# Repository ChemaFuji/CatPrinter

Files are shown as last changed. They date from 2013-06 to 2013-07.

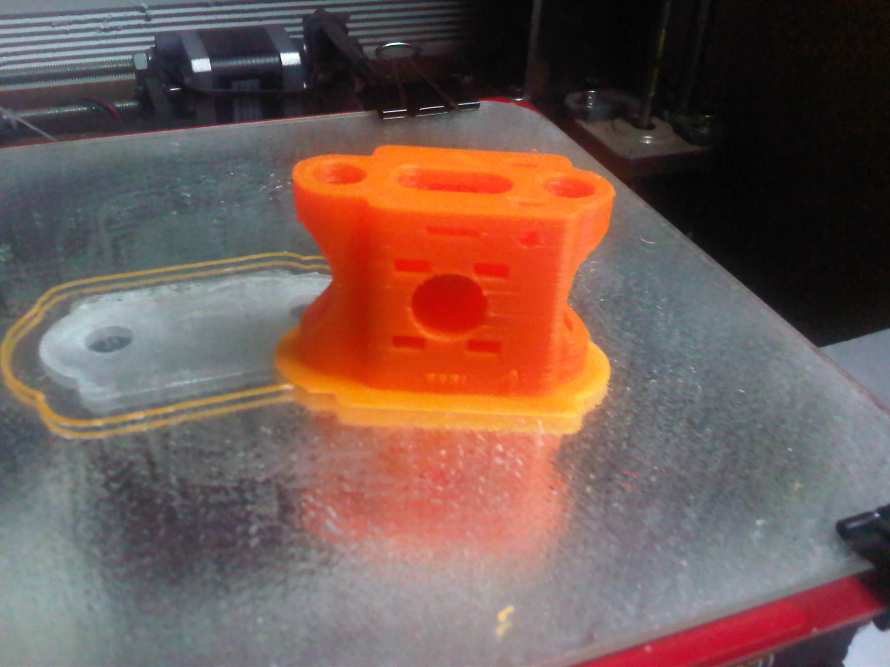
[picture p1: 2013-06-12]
images/carro X.jpg

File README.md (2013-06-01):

# CatPrinter

CatPrinter is a 3D printer core XY based that aims to be powerful, stable, open and fast. The stage is very early, so please don't print or try to mount anything from this if you don't know what are you doing...

There are a site to check this and other projects:

 * https://sites.google.com/a/pentabyte.es/chemadesigns/

There is also a twitter account for my projects, [@ChemaPenta](http://www.twitter.com/ChemaPenta).

Feel free to email me personally at chema@pentabyte.es

Chema

[Flattr this][1]

[1]: http://flattr.com/thing/1403970/Chema-open-designs
[2]: http://api.flattr.com/button/button-static-50x60.png

# CatPrinter

Catprinter es una impresora 3D del tipo coreXY que pretende ser potente, estable, open source y rápida. Esta en un estadio muy temprano así que no imprimas o intentes montar nada de aquí si no estás muy seguro de lo que haces.

Habrá muchos cambios en los próximos días.
Hay una web donde mirar éste y otros proyectos:

 * https://sites.google.com/a/pentabyte.es/chemadesigns/

También hay una cuenta de twitter para mis proyectos, [@ChemaPenta](http://www.twitter.com/ChemaPenta).

M podéis mandar emails a mí personalmente a chema@pentabyte.es

Chema.

[Flattr this][1]

[1]: http://flattr.com/thing/1403970/Chema-open-designs
[2]: http://api.flattr.com/button/button-static-50x60.png

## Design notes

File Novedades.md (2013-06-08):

#Novedades

Cambio completamente las fijaciones de las esquinas y los carros-Y para conseguir mayor volumen de impresión en menor espacio. Las primeras pruebas con cojinetes Igus funcionan bien. En breve voy a cambiar casi todas las piezas.

Cambiadas carro_x, carro_y y las y_end (motor e idle). Cambio los nombres de casi todas las piezas para ser más congruentes con la estructura actual.

Mejoradas las y_end con mejores sistemas de fijación de bridas. 

Agregado tensor en el y_end_idler.

Mejoradas las piezas de fijación correa en carro_x.

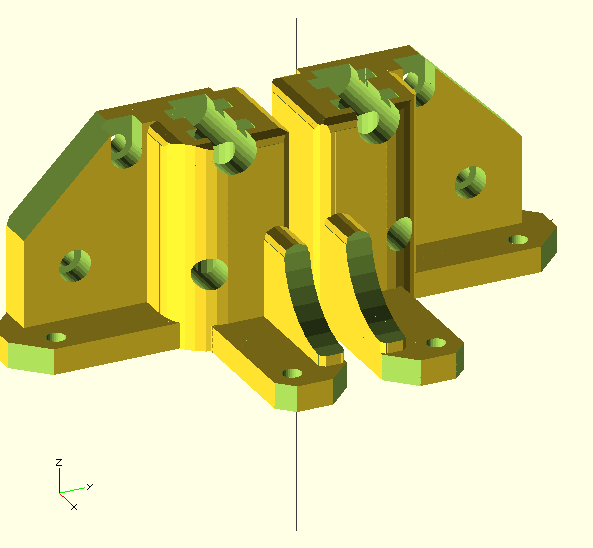
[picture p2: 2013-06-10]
images/y_end_motor.png

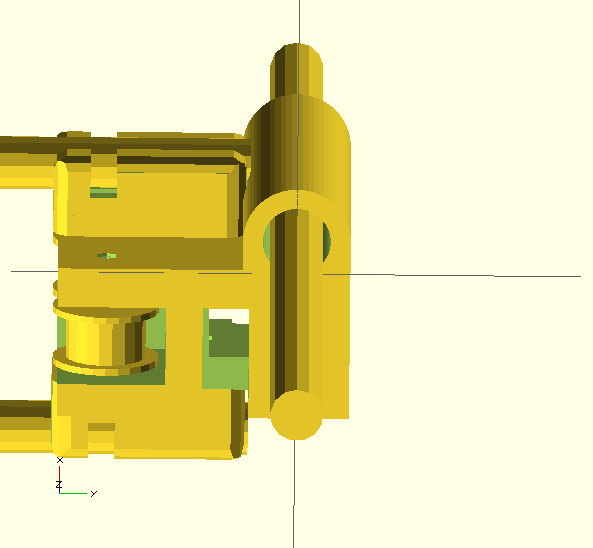
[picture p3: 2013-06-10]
images/carro_y.png

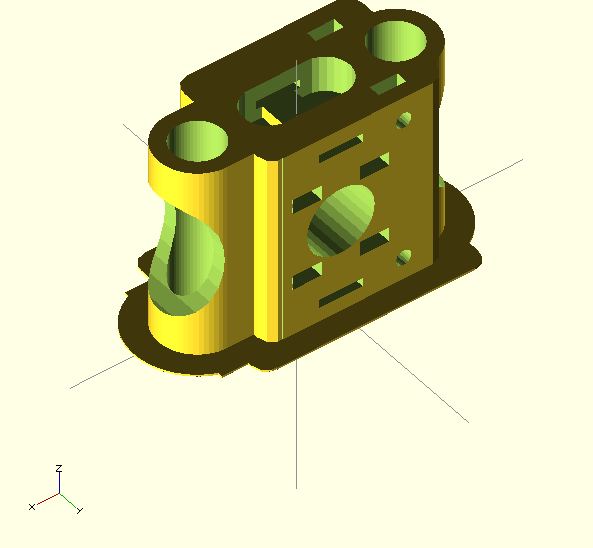
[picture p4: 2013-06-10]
images/carro_x.png

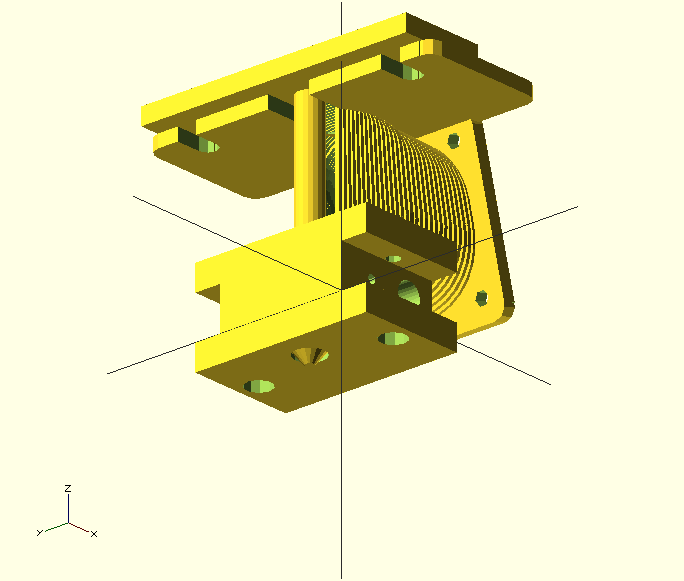
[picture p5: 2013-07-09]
images/CatNozzle with fan.png

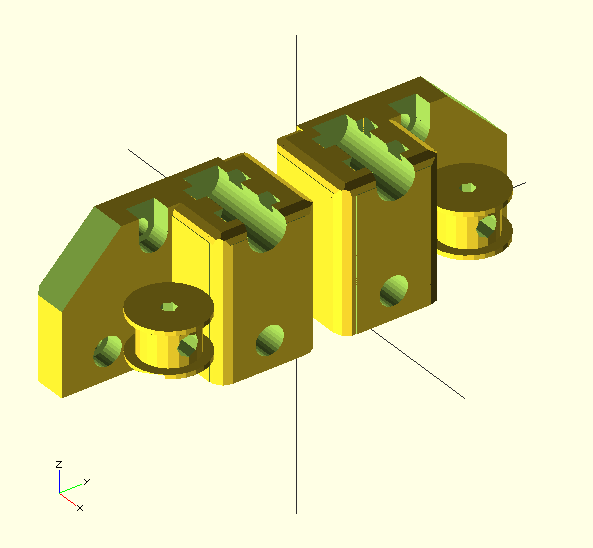
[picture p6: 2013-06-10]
images/y_end_idler.png

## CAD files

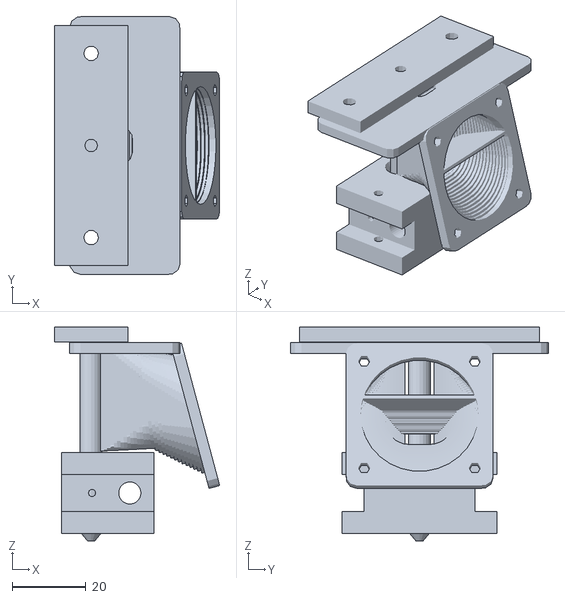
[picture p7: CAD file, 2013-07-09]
acc/CatNozzle_with_fan.stl
44.9 x 70.0 x 58.0

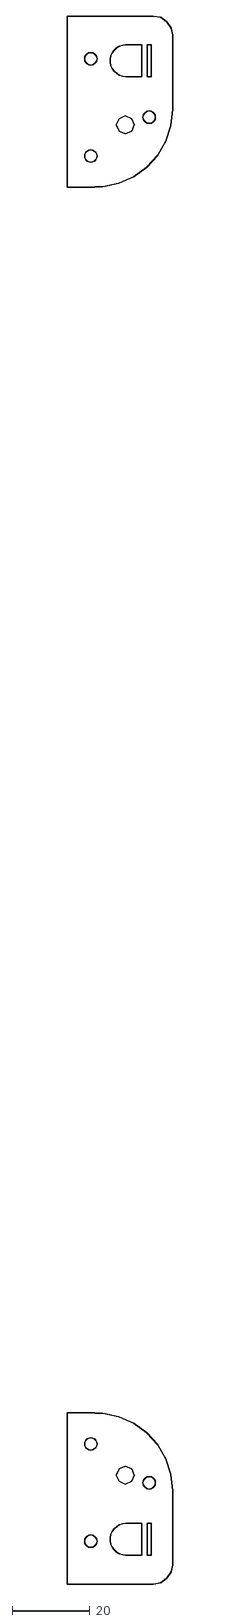
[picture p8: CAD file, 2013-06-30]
extra/Idle side.dxf
27.0 x 403.0

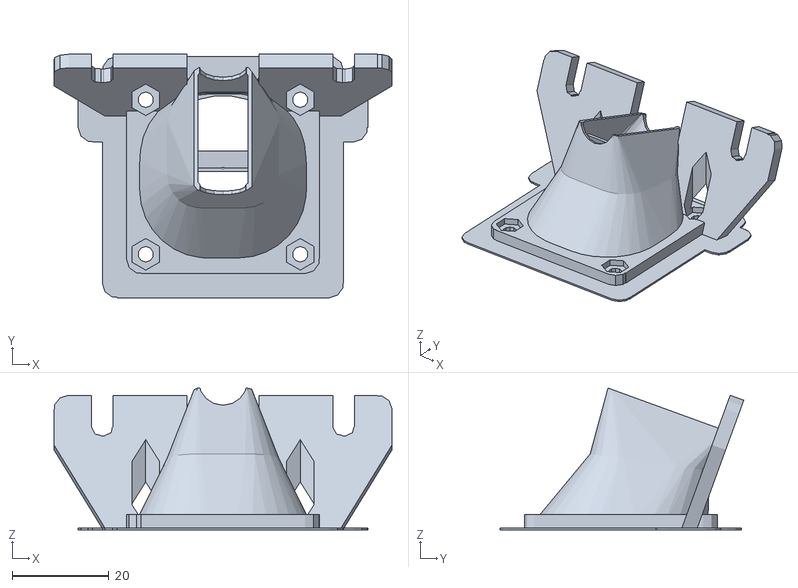
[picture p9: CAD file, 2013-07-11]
imprimir/catnozzle_fan_brim.stl
70.0 x 50.4 x 29.4

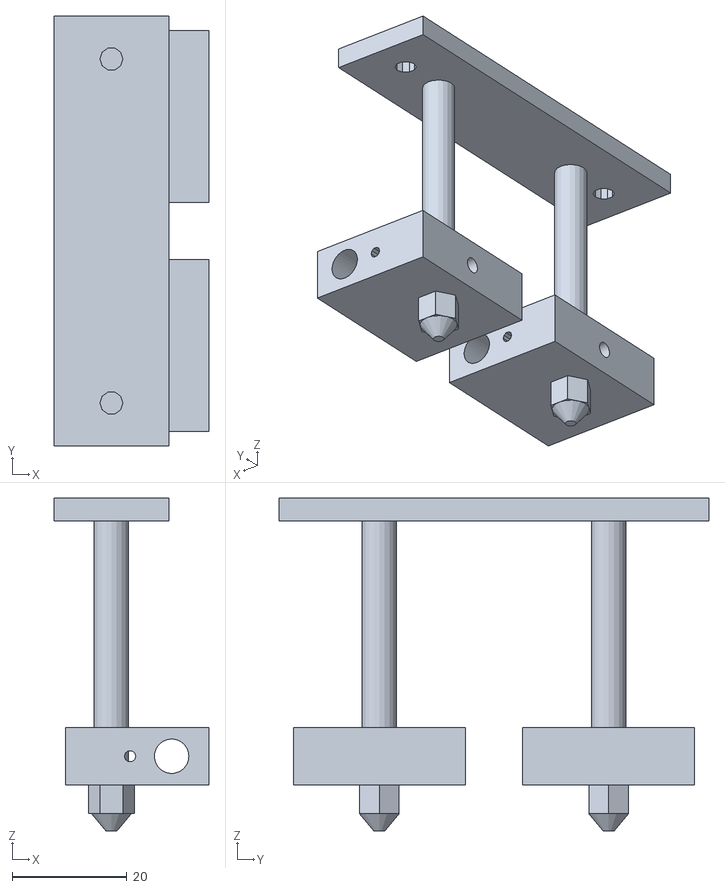
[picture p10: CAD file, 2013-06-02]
acc/CatNozzle_doble.stl
27.0 x 75.0 x 58.0

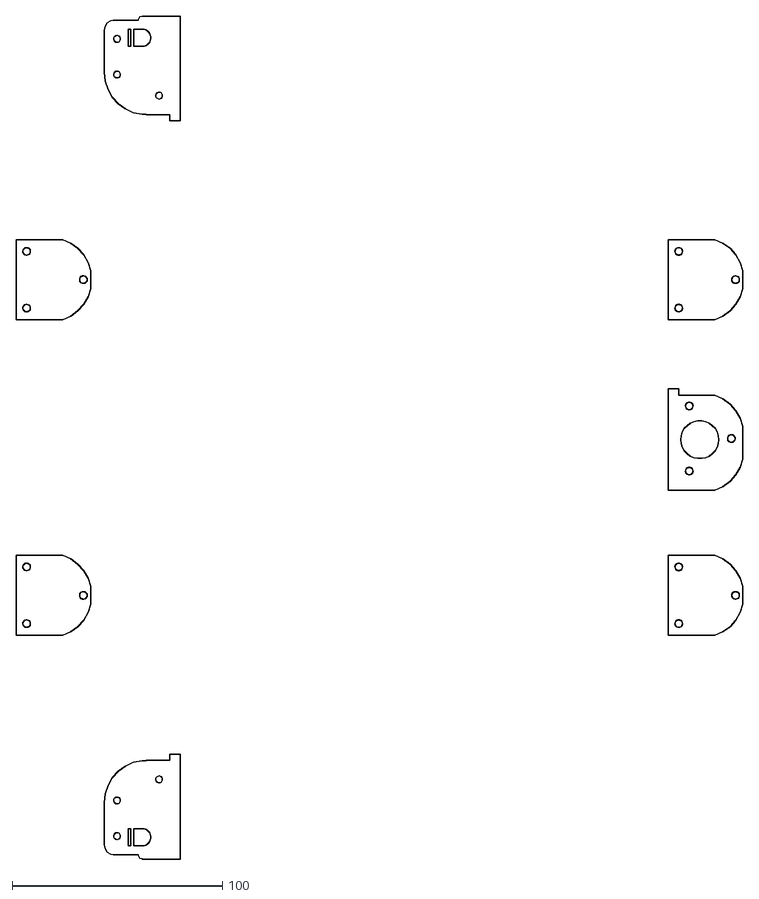
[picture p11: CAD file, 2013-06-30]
extra/motor side.dxf
345.5 x 400.7

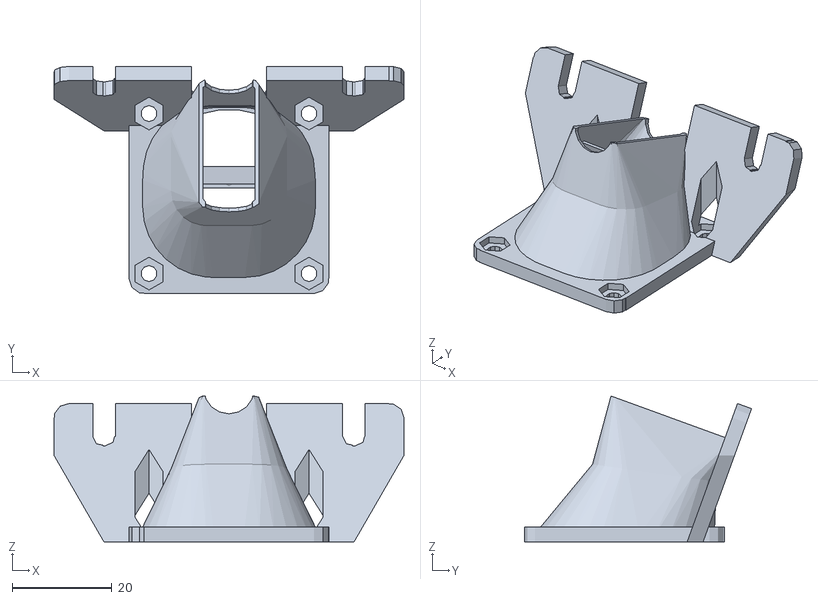
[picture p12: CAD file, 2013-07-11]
imprimir/catnozzle_fan.stl
70.0 x 45.4 x 29.2

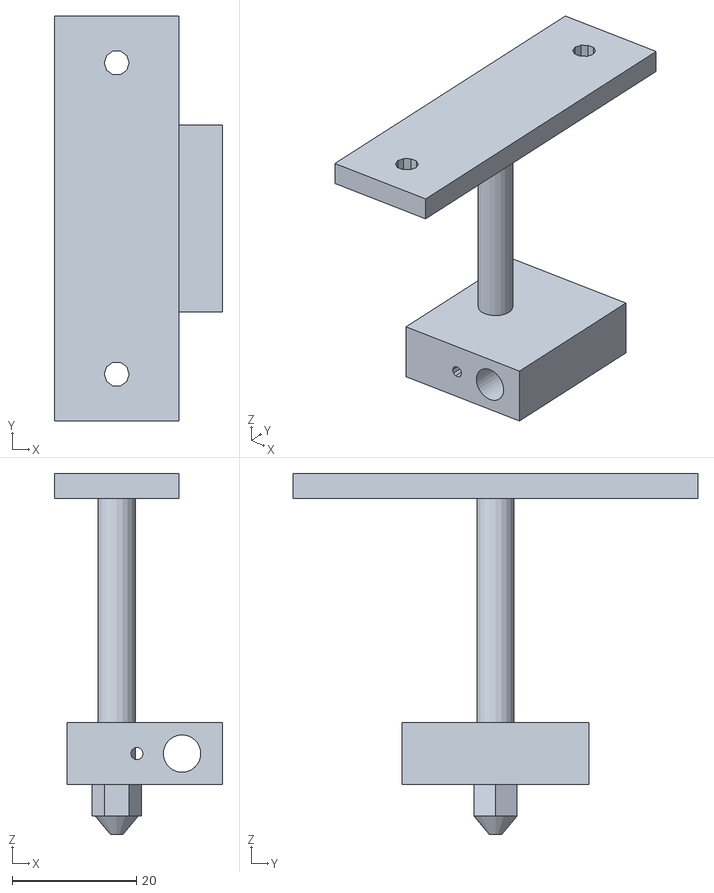
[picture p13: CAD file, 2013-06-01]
acc/CatNozzle2.stl
27.0 x 65.0 x 58.0

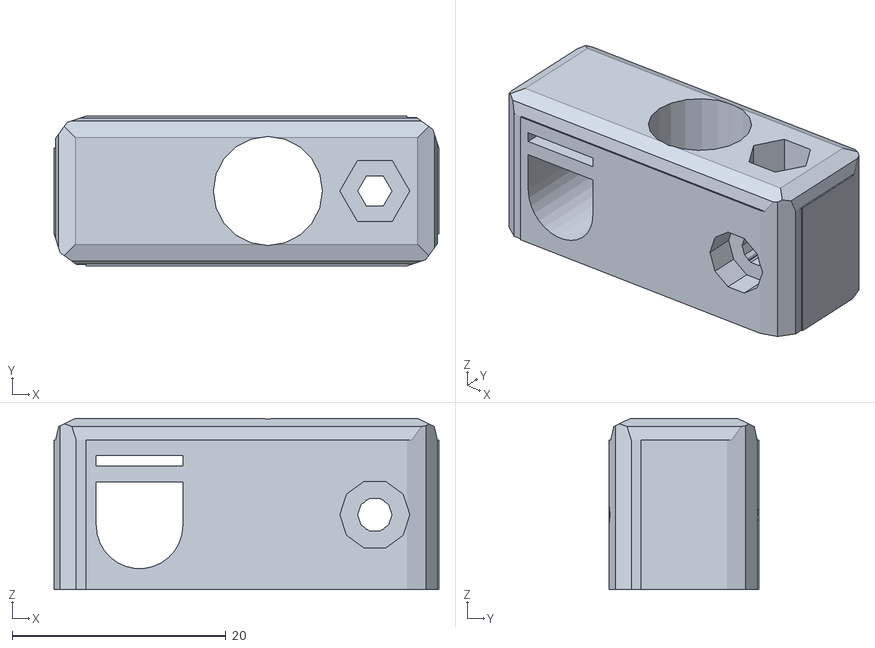
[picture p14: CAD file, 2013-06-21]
extra/Calibrate_printer.stl
36.0 x 14.0 x 16.0

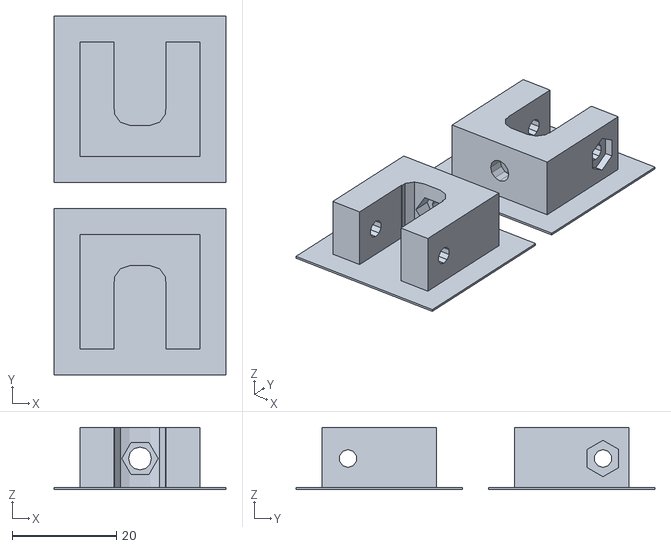
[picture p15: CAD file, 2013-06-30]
imprimir/tensor-y.stl
33.0 x 69.0 x 12.0

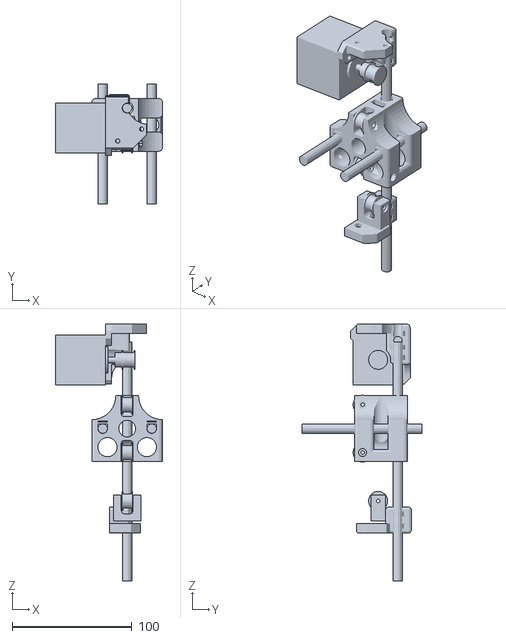
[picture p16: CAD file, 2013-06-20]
extra/carro-y_new-test.stl
89.5 x 100.0 x 215.0

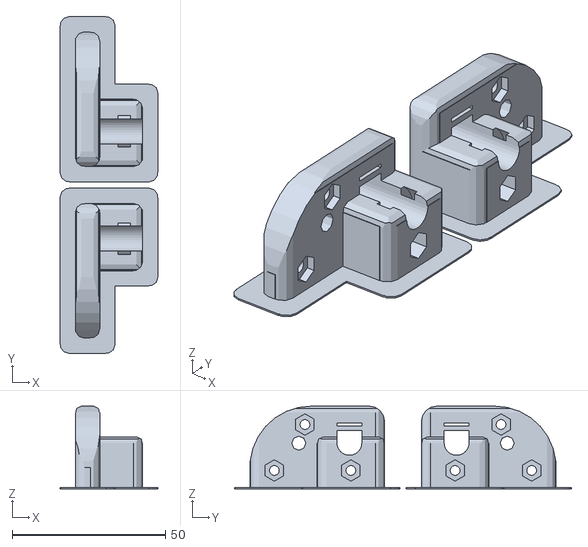
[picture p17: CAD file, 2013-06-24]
imprimir/y_end_idler_brim.stl
32.0 x 110.0 x 27.0

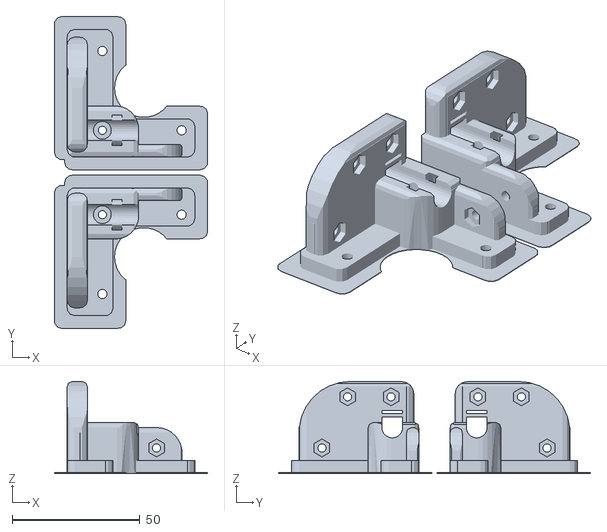
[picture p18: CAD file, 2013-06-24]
imprimir/y_end_motor_brim.stl
60.0 x 122.0 x 36.0

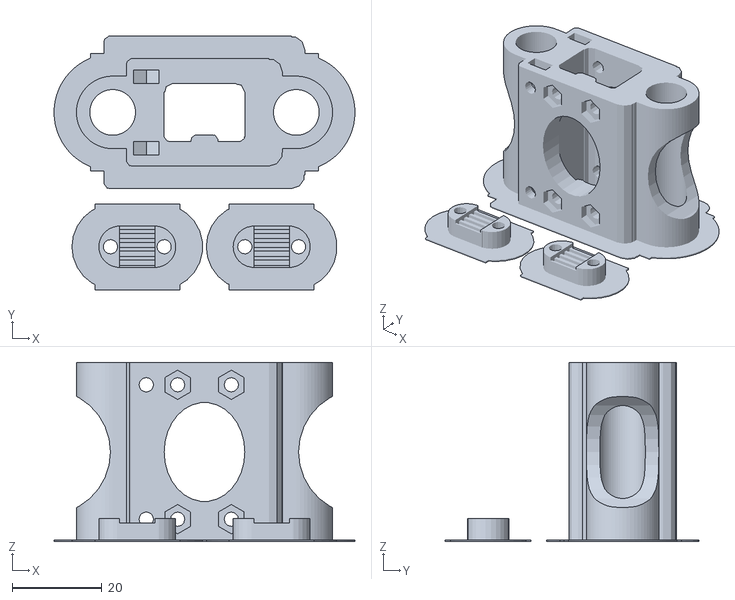
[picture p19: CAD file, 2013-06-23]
imprimir/carro-x_new_brim.stl
67.2 x 56.6 x 40.0

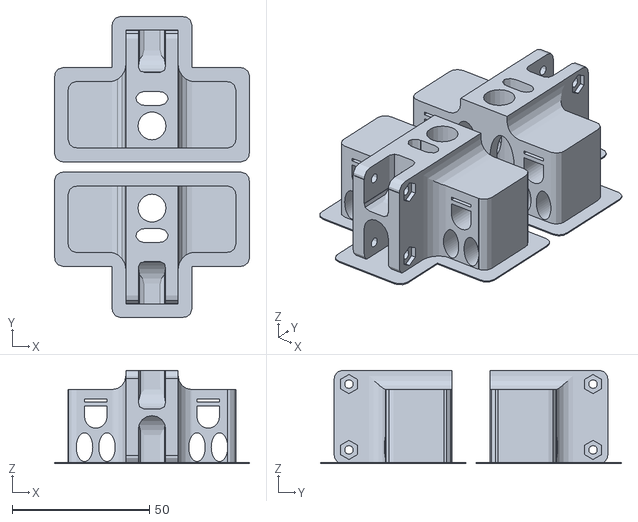
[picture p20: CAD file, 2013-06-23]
imprimir/carro-y_new3_brim.stl
71.1 x 109.8 x 34.0

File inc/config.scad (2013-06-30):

// New Printer by Chema
// GNU GPL v3

// Mod basado en
// Josef Průša
// josefprusa@me.com
// prusadjs.cz
// http://www.reprap.org/wiki/Prusa_Mendel
// http://github.com/prusajr/PrusaMendel

margen=0.2; //margen en diámetro para los agujeros
brimh=0.4; //altura de capa para brim
brimw=0; //cuanto brim (5)

// Extremos eje Y
altura = 20; //original 40
fondo = 22; //longitud de los soportes de barras
ancho = 18;
bajos = 6;
extra_long=6; //long. extra del soporte barra en el extremo motor

grueso=5;

//Carro Y
	yc_alto=19; //33-10-6+2;
	
	yc_ancho=43;
	sep_pol=24; //separación entre ejes de poleas
	sep_polea=24;
	yc_largo=sep_pol+10;
	
	//altura polea respecto barra superior
	//pos barra altura-2 del motor
	//pos polea (shaft motor 24mm, polea 18mm alto) 6mm sobre motor (+-2mm)
	//espacio para polea (altura) = 12-14mm
	
	//x_rod_distance = (altura-2+grueso-yc_alto)*2; //29.25*2;
	//x_rod_distance = 29.25*2-10;
	x_rod_distance = 31+10; //separación de barras eje X
	y_rod_distance = 55; //separación de barras eje Y (en caso de dos barras) Obsoleto
	diam_x=8.1; //Diámetro de la barra lisa del eje X 8.1 PLA, 8.4 ABS
	belt_space=10; //paso para las correas


bearing_diameter = 10+margen; //diámetro de los cojinetes lineales
thinwall = 2+1; //pared en los cojinetes
bearing_size = bearing_diameter + 2 * thinwall;

sep_tensor=18.5-2; //espacio entre el eje del tensor y la barra lisa eje Y

//Medidas bearing 623
623_id=3;
623_od=10;
623_h=4;

//Carro X
	xc_largo=40; //largo del carro X
	//xc_ancho=altura-2+grueso-yc_alto;
	xc_ancho=sep_pol; //espacio entre ejes poleas en carro Y (==ancho carro X) (24)
	//fijaciones correa carro X
	grueso_fijacion=4; //este grueso incluye el grosor de la correa (0.75mm para GT2==belt_grueso)
	ancho_fijacion=12; //entre centros de los agujeros
	largo_fijacion=10; 
	red_fijacion=0.4; //cuanto más pequeña es la fijación con respecto a su hueco en el carro X
	fge=1.0; //grueso extra de la fijación correa
	tbf=3.5; //espacio entre fijación y su tuerca

// Carro Z
	rfn=true; //¿lleva refuerzo?
	grm=6; //grosor material refuerzo
	sep_z=150; //separación entre las barras
	fromw=29.5; //separación barra lisa de la pared
	cz_fondo=20; //fondo del carro Z
	cz_alto=50;
	cz_largo=sep_z+20;
	 esp=6/2; //la mitad del espesor que queremos en la viga
	 cur=cz_fondo/2-esp;
	longZ=310; //longitud del eje Z (esto se ha de poder variar)

// PLEASE SELECT ONE OF THE CONFIGURATIONS BELOW
// BY UN-COMMENTING IT

// Uncomment for metric settings
// METRIC METRIC METRIC METRIC METRIC METRIC METRIC METRIC 

include <metric.scad>;

// Uncomment for imperial settings
// IMPERIAL IMPERIAL IMPERIAL IMPERIAL IMPERIAL IMPERIAL IMPERIAL 

//include <sae.scad>;

// LM8UU
linear = false;


// CHANGE ONLY THE STUFF YOU KNOW
// IT WILL REPLACE DEFAULT SETTING

// RODS

// threaded_rod_diameter = 0;
// threaded_rod_diameter_horizontal = 0;
// smooth_bar_díameter = 0;
// smooth_bar_díameter_horizontal = 0;

// Nuts and bolts

// m8_diameter = 0;
// m8_nut_diameter = 0;

// m4_diameter = 0;
// m4_nut_diameter = 0;

// m3_diameter = 0;
// m3_nut_diameter = 0;

// Bushing holder

// bushing_core_diameter = smooth_bar_díameter;
// bushing_material_thickness = 0;


///counted stuff
m3_nut_diameter_bigger = ((m3_nut_diameter  / 2) / cos (180 / 6))*2;
m5_nut_diameter_bigger = ((m5_nut_diameter  / 2) / cos (180 / 6))*2;

// funciones 
include <funciones.scad>


// Select your belt type ******************************************************

//T2.5
//belt_tooth_distance = 2.5;
//belt_tooth_ratio = 0.5;

//T5 (strongly discouraged)
//belt_tooth_distance = 5;
//belt_tooth_ratio = 0.75;

//HTD3
//belt_tooth_distance = 3;
//belt_tooth_ratio = 0.75;

//MXL
//belt_tooth_distance = 2.032;
//belt_tooth_ratio = 0.64;

//GT2
belt_tooth_distance = 2;
belt_tooth_ratio = 0.5;
belt_grueso = 0.75;
belt_ancho = 6;

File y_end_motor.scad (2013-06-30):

// esquina para new printer by Chema
// Mod basado en
// PRUSA iteration3
// Y axis motor end
// GNU GPL v3
// Josef Průša <iam@josefprusa.cz> and contributors
// http://www.reprap.org/wiki/Prusa_Mendel
// http://prusamendel.org
 
include <inc/config.scad>
extra_long=6;
impresion=true;

module esquinam_base(){
 translate([0,-3,0]) cube_fillet([8,40+5,34+2],top=[20,2,5,2]); // plate touching the back wall
 translate([0+4,-5,0]) 
 cube_fillet([41,5.01,22-4], vertical=[1,1,1,1], top=[2,2,2,10], center=false); //refuerzo lateral
 
 translate([0+4,-5,0]) cube_fillet([50-4,15,5]); // plate touching the motor (1/2)
 translate([0,-5+4,0]) cube_fillet([18,50-4,5]); // plate touching the motor (2/2)
	translate([11+extra_long/2,5,altura/2]) rotate([0,0,90]) 
	//soporte barra eje Y
	cube_fillet([ancho+2,fondo+extra_long,altura], vertical=[3,3,3,9], top=[2,2,2,2], center=true);
 if (brimw>0){
 translate([0+4-brimw,-5-brimw,0]) cube_fillet([50-4+brimw*2,15+brimw*2,brimh]); // plate touching the motor (1/2)
 translate([0-brimw,-5+4-brimw,0]) cube_fillet([18+brimw*2,50-4+brimw*2,brimh]); // plate touching the motor (2/2)
	translate([11+extra_long/2,5,altura/2]) rotate([0,0,90]) 
	//soporte barra eje Y
	cube_fillet([ancho+2,fondo+extra_long,altura], vertical=[3,3,3,9], top=[2,2,2,2], center=true);

 }
}

module esquinam_holes(){

 // Frame mounting screw holes
 translate([10,6,30]) rotate([0,90+180,0])
 screw(r=m3_diameter/2,r2=m3_nut_diameter, slant=false, head_drop=4, h=20, $fn=20,$fnn=6);
 translate([10,13+20,10]) rotate([0,90+180,0])
 screw(r=m3_diameter/2,r2=m3_nut_diameter, slant=false, head_drop=4, h=20, $fn=20,$fnn=6);
 translate([10,13+10,10+20]) rotate([0,90+180,0])
 screw(r=m3_diameter/2,r2=m3_nut_diameter, slant=false, head_drop=4, h=20, $fn=20,$fnn=6);

 //tornillo lateral
 translate([35,1,10]) rotate([0,90+180,90])
 screw(r=m3_diameter/2,r2=m3_nut_diameter, slant=false, head_drop=3, h=20, $fn=20,$fnn=6);


  // Hueco para barra lisa
  translate([2-3,5.5,altura-2]) rotate([270,0,270]) pushfit_rod(diam_x,100);
  // Bridas
	translate([16+3.5,5.5,altura-6.1])
	rotate([0,90,0])
   	brida(r=6);

	//Hueco centro para motor
	translate([30,22,-1])
	cylinder(r1=11.5,r2=10,h=30,$fn=30);

 // motor mounting
 translate([25+4.3,21,-1]){
 //translate([15.5,15.5,-1]) cylinder(h = 20, r=1.8, $fn=30);
 
 translate([15.5,-15.5,-1]) cylinder(h = 20, r=1.8, $fn=30);
 translate([-15.5,15.5,-1]) cylinder(h = 20, r=1.8, $fn=30);
 translate([-15.5,-15.5,47]) //cylinder(h = 200, r=1.8, $fn=30);
 rotate([180,0,0]) screw(r=m3_diameter/2, slant=false, head_drop=41, h=70, $fn=20);
 }

}

// Final part
module esquinam_holder(){
 difference(){
  esquinam_base();
  esquinam_holes();
 }
}

if (impresion){
esquinam_holder();
translate([0,-22,0]) mirror([0,1,0])
esquinam_holder();

//translate ([30,22,8]) rotate ([180,0,0]) {
//nema17(h=8,holes=0,shadow=5, polea=12);}
}

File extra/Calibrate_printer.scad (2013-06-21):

// New printer MOD by Chema

// Pieza para pruebas
// GNU GPL v3


include <inc/config.scad>
use <inc/bearing.scad>

module base(){
cube_fillet([36,14,16],top=[2,2,2,2]);
}

module agujeros(){

	translate ([8,20,6]) 
	rotate ([90,180,0]) 
	pushfit_rod(diam_x,50);

	translate([20,7,-5])
	cylinder(r=bearing_diameter/2,h=100,$fn=20);
	
	translate ([30,7,20]) rotate ([180,0,0]) 
	 screw(r=m3_diameter/2, r_head=m3_nut_diameter/2, slant=false, head_drop=10, h=50, $fn=6);

	translate ([30,22,7]) rotate ([90,0,0]) 
	 screw(r=m3_diameter/2, r_head=m3_nut_diameter/2, slant=false, head_drop=10, h=50, $fn=6);

	translate ([30,-7,7]) rotate ([270,0,0]) 
	 screw(r=m3_diameter/2, r_head=m3_nut_diameter/2, slant=false, head_drop=10, h=50, $fn=10);

}

difference(){
	base();
	agujeros();
}

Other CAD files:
imprimir/carro-y_new3.stl
imprimir/carro-y_new2_brim.stl
imprimir/carro-y_new_brim.stl
carro-x.scad
Z-axis.scad
acc/CatNozzle.scad
acc/CatNozzle_doble.scad
carro-x_new.scad
carro-y.scad
carro-y_new-test.scad
carro-y_new.scad
carro-y_new2.scad
carro-y_new3.scad
carro-y_old.scad
extra/CatPrinter_complete_v1.scad
extra/CatPrinter_complete_v2.scad
extra/catnozzle_fan.scad
fijaciones X.scad
fijaciones esquina.scad
imprimir/Y-end-motor.stl
imprimir/Z-axis.stl
imprimir/Z-axis_brim.stl
imprimir/carro-x.stl
imprimir/carro-x_aligerado.stl
imprimir/carro-x_brim_aligerado.stl
imprimir/carro-x_con_brim.stl
imprimir/carro-y.stl
imprimir/fijaciones carro-x.stl
imprimir/old to be deleted/Y-end-motor.stl
imprimir/old to be deleted/Z-axis.stl
imprimir/old to be deleted/carro-x.stl
imprimir/old to be deleted/carro-x_aligerado.stl
imprimir/old to be deleted/carro-x_brim_aligerado.stl
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

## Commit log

2013-06-01 First upload
    Publishing files
    [CatNozzle.scad, CatNozzle.stl, CatNozzle2.stl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]
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2013-06-02 mas medidas
    Ajustando medidas para aprovechar al máximo el espacio sin perder
    fiabilidad
    [carro-y.stl, carro-y_55mm.stl, config.scad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]
2013-06-02 catnozzle doble
    Agregado nuevo catnozzle doble, para montar 4 hotends
    [CatNozzle_doble.scad, CatNozzle_doble.stl]
2013-06-02 623
    Agregadas las medidas del 623 para las poleas, poleas.scad para crear
    [config.scad]
2013-06-02 Poleas
    Modificada la función de polea para crear las que conducen la correa.
    También creado el archivo poleas.scad que genera 8 unidades (sólo se
    necesitan 6)
    [funciones.scad, poleas.scad]
2013-06-02 cambio nombre carro-Y
    Para unificar, he cambiado el nombre de x-end a carro-y
    [carro-y.scad]
2013-06-02 new-size
    Nuevas medidas del carro-x
    [carro-x.scad]
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2013-06-08 Cleaning
    Make clean and delete some old files
    [Y-corner-motor.stl, Y-corner-motorn.stl, Y-corner.stl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]
2013-06-08 printing
    New files ready to print
    [Y-end-motor.stl, tensor-y.stl, y_end_idler.scad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]
2013-06-08 News
    Novedades en varias piezas, nueva función cube-fillet con inversión.
    [carro-y.scad, funciones.scad]
2013-06-09 brim
    added brim to some pieces to make easier ABS print. We need to test...
    [bearing.scad, carro-x.scad, carro-x_con_brim.stl]
2013-06-10 new carro_X
    Nuevas medidas, nuevo planteamiento tras problemas con slicer
    (kisslicer, sclic3r y cura).
    [carro-x.scad, carro-x.stl, carro-x_con_brim.stl]
2013-06-10 BRIM
    Cambio algunas funciones para implementar brim en las piezas que se han
    de imprimir en ABS (carro X)
    [bearing.scad, funciones.scad]
2013-06-10 Maintenance
    Ordenando constantes y limpiando inutilidades
    [config.scad, metric.scad]
2013-06-10 ultimos retoques
    Los últimos retoques al carro X (creo)
    [carro-x.scad, carro-x_aligerado.stl, carro-x_brim_aligerado.stl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]
2013-06-10 corregido
    Un pequeño error de posición del tensor
    [y_end_idler.scad]
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2013-06-15 fijaX
    Correcciones a las fijaciones de correa carroX y crear nuevo archivo
    exclusivo
    [fijaciones X.scad, fijaciones carro-x.stl, funciones.scad]
2013-06-18 Remodelado
    Para hacer más fuerte el enlace ejeX=ejeY cambio diversas cosas como el
    carro Y, la altura de la barra de los ejes Y
    [carro-y_new.scad, config.scad, y_end_motor.scad]
2013-06-18 Fan
    Un ventilador para el hotend, por terminar
    [catnozzle_fan.scad]
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2013-06-19 new carroY
    El nuevo carro Y implica cambios en todas las piezas que lo sustentan.
    Se ha remodelado el y-end-motor y se ha quitado algo de plástico del
    carro Y.
    [carro-y_new.scad, config.scad, y_end_motor.scad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]
2013-06-20 testing
    carro Y con sus ends para ver acotaciones
    [carro-y_new-test.scad, carro-y_new-test.stl]
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2013-06-21 Cleaning
    Poniendo un poco de orden en casa, para que sea más fácil cambiar
    parámetros...
    [config.scad, funciones.scad, metric.scad]
2013-06-21 Z Axis
    Todo lo necesario para el eje Z
    [Z-axis.scad, Z-axis.stl]
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2013-06-23 new_carroY
    Nuevo carro Y para evitar warping y usar menos plástico
    [carro-y_new2.scad, carro-y_new2_brim.stl]
2013-06-23 new concept
    Nuevo concepto carro X e Y, poleas más juntas, se reduce el tamaño de
    las piezas. las correas pasan por el interior del carro X
    [CatPrinter_complete_v2.scad, carro-x_new.scad, carro-x_new_brim.stl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]
2013-06-23 Change name
    Cambio de nombre y de sitio, por mantener ordenado
    [CatPrinter_complete_v1.scad]
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2013-06-23 new concept
    Añadido el nuevo concepto de carroX y carroY
    [CatPrinter_complete_v2.scad]
2013-06-23 fix
    Corregido pequeño problema de posición para imprimir
    [carro-x_new.scad, carro-x_new_brim.stl]
2013-06-24 new concept
    Nuevo concepto, barra Y más baja (a la altura de la correa). Fijación
    de la barra "stronger"
    [y_end_idler.scad, y_end_idler_brim.stl, y_end_motor.scad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]
2013-06-30 pequeños ajustes
    Para poder parametrizar la altura de impresión
    [CatPrinter_complete_v2.scad, Z-axis.scad, config.scad]
2013-06-30 nuevo tensor Y
    Reforzado para mejorar el esfuerzo que puede soportar
    [tensor-y.scad, tensor-y.stl]
2013-06-30 doc
    Agregados comentarios al código a modo de docuemtnación para que
    cualquiera pueda entenderlo y así ser más fácil la modificación
    [carro-x_new.scad, carro-y_new3.scad, config.scad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]
2013-06-30 2D print
    proyecciones 2D de las piezas de fijación de las barras Y y Z para
    imprimirlas en papel y poder montarlas con exactitud.
    [Idle side.dxf, motor side.dxf]
2013-06-30 cleanning
    Quito versiones antiguas para no confundir a quien quiera hacer una
    impresora de estas
    [Y-end-motor.stl, Z-axis.stl, carro-x.stl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]
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2013-06-30 parametric
    Parametrizando la presentación para poder crear la impresora a
    cualquier tamaño...
    [CatPrinter_complete_v2.scad]
2013-07-02 cleaning
    Only to have a clean master view
    [CatPrinter_complete_v2.scad, carro-y_new3.scad, y_end_idler.scad]
2013-07-09 CatNozzle news
    Ajustes de CatNozzle, con sandwitch de Trespa y ventilador
    [CatNozzle.scad, CatNozzle_with_fan.stl, catnozzle_fan.scad]
2013-07-09 Mejora impresion
    La pletina empezaba en el aire...
    [catnozzle_fan.scad, catnozzle_fan.stl]
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2013-07-11 some refine sizes
    Ajustes de medidas y cambio sistema para generar el conducto (hull)
    [CatNozzle.scad, catnozzle_fan.scad, catnozzle_fan.stl]
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
